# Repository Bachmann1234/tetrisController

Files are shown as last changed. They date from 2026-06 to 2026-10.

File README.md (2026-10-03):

# Tetris Controller

A split Tetris controller built around a Raspberry Pi Pico running CircuitPython. Presents itself as a USB keyboard so it works with any Tetris game (TETR.IO, Tetris Effect, Jstris, etc.) with no remapping required.

## Hardware

- Raspberry Pi Pico (RP2040) — lives in the right half
- 8 buttons, direct-wired (no matrix, no diodes)
- GX16-8 cable connecting the two halves
- LEDs are wired directly to power (no firmware control)

### Wiring

All buttons: **SW+ → GPIO**, **SW− → GND**. Internal pull-ups are enabled in firmware, so LOW = pressed.

| Button | GPIO | Half  | Key sent |
|---|---|---|---|
| Soft Drop | GP2  | Left  | Down Arrow |
| Right | GP3  | Left  | Right Arrow |
| Left | GP4  | Left  | Left Arrow |
| Hard Drop | GP5  | Left  | Space |
| Rotate CCW | GP6  | Right | Z |
| Rotate CW | GP7  | Right | X |
| Hold | GP8  | Right | C |
| Zone / Start | GP9  | Right | A |

The left-half buttons reach the Pico through the GX16-8 cable but are electrically identical to the right-half buttons.

## Enclosure: Printed by PCBWay

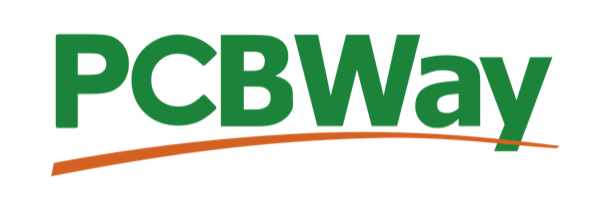
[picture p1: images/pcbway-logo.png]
PCBWay


[PCBWay](https://www.pcbway.com/) saw the first version of this controller and reached out about sponsoring a print. This inspired me to revise the design.

PCBWay is a prototyping and small-batch manufacturer. Along with PCB fabrication and assembly, they offer 3D printing (SLA, SLS, MJF, FDM, and metal), CNC machining, sheet metal, and injection molding.

I printed my first version in PETG on my Prusa Core One. It proved the layout, but it still looked like a prototype. For the next revision I wanted something that felt solid and a bit more professional.

### Ordering

I exported the box and button panel from Fusion 360. I went through the ordering process which felt intimidating at first but ultimately was pretty straightforward. I wanted something that I could not print myself so I went with Nylon PA12.

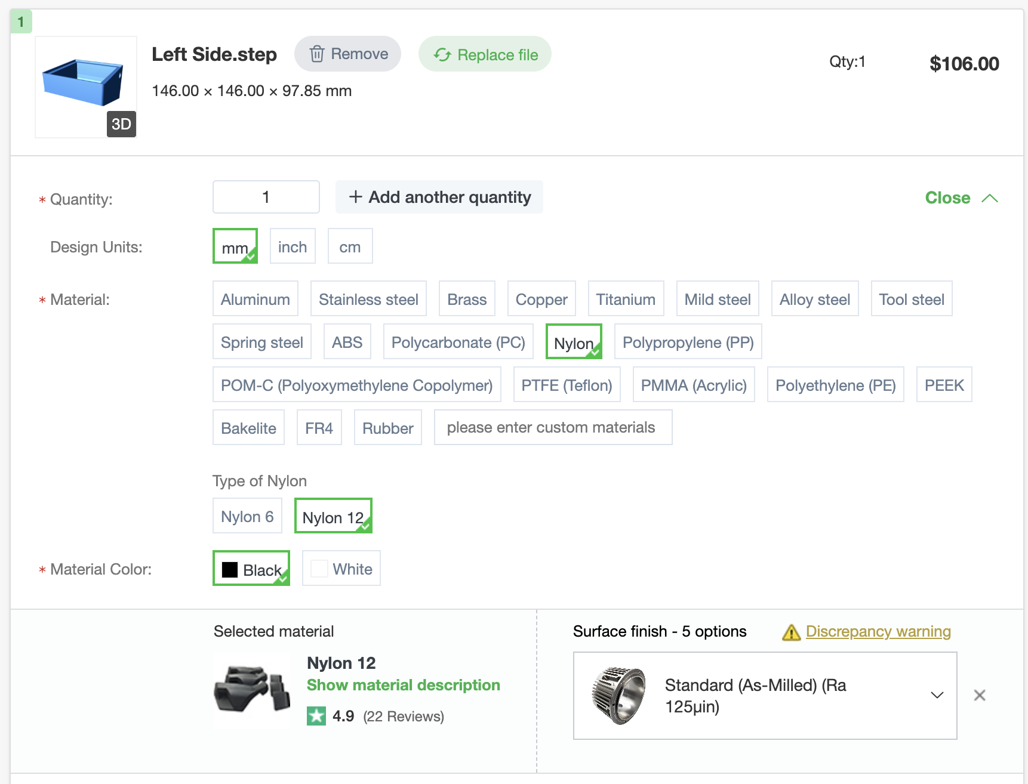
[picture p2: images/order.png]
Order Form


One of their engineers reached out and warned me that there was a chance of some warping. I was fine with this, since my tolerances were loose enough to absorb a little warping.

It was very comforting to get this feedback instead of just receiving the item and being disappointed in the results.

So far I've gotten the right side of the controller. It arrived in a nondescript box and was extremely well protected with foam. When I took it out I was really impressed. It looks incredible and it feels almost as if I had it printed in ceramic. I just love the feel and the sound when I tap it.

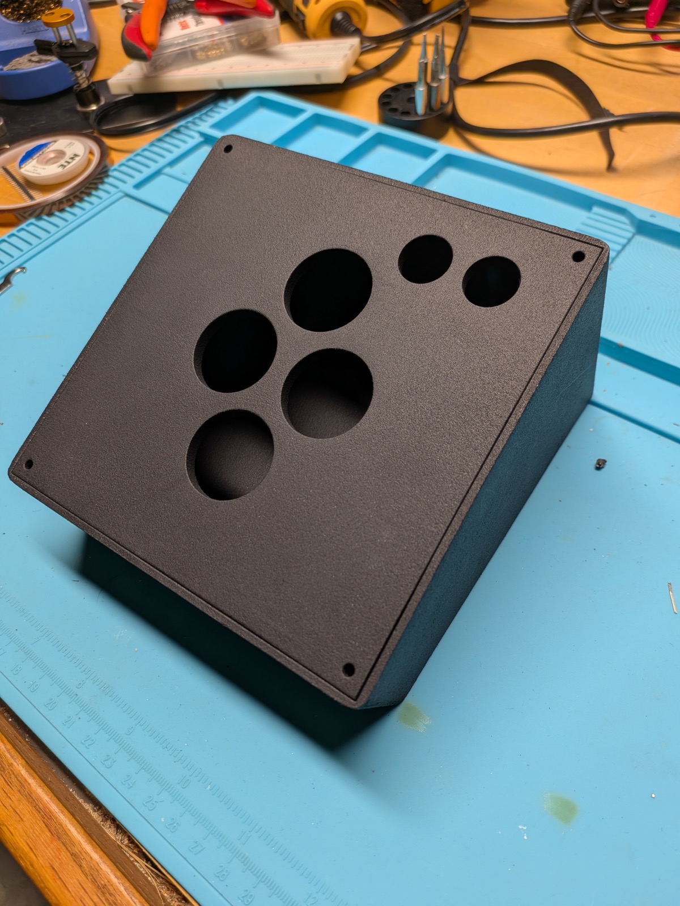
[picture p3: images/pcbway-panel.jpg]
Button panel seated on the box


The inside came out just as cleanly as the outside. The screw bosses on the Pico mounting rail are fully formed, and the rectangular USB cutout has sharp corners.

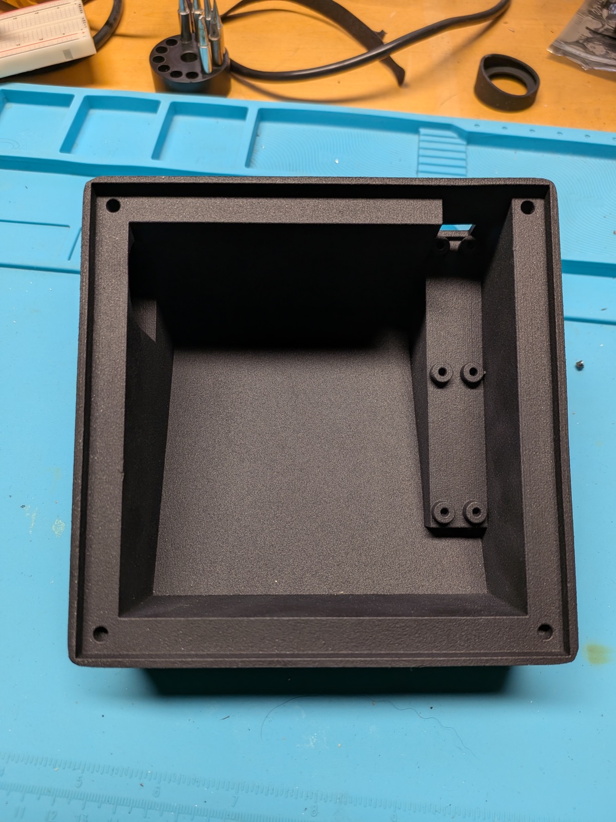
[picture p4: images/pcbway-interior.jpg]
Inside the box: Pico mounting rail, USB cutout, and panel lip


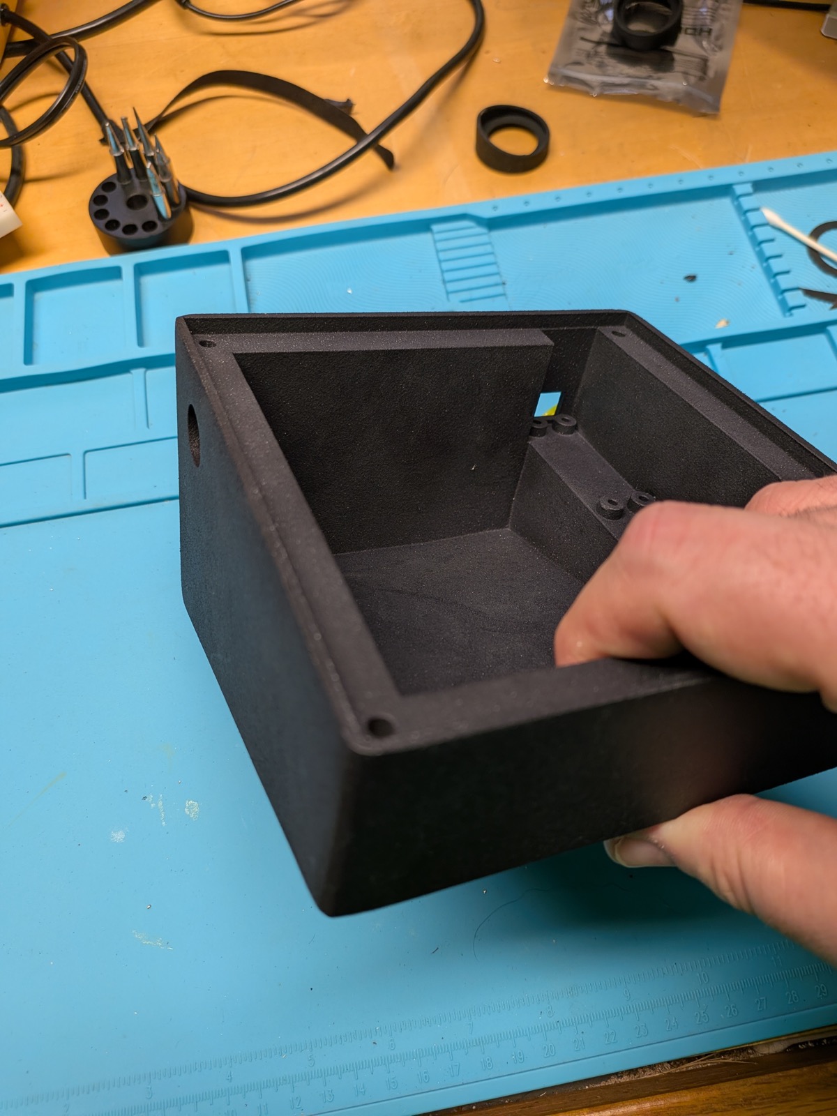
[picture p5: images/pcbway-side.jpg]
Side view showing the GX16-8 connector hole


The pieces fit together without any sanding, which was a relief. The button holes came out perfectly! They left no sign of supports.

I am looking forward to doing the second half and assembling the final piece. Once that is done I will have a controller that really changes how I play Tetris and other games.

### Why PCBWay

I have tried to get quotes for small projects. Small quantities are just not worth it to most manufacturers and the quotes come back in the thousands. PCBWay gives me an approachable way to make something just for me while having the quality of a professional product.

## Setup for a new Pico

### 1. Flash CircuitPython

1. Download the UF2 for your board:
   - Pico (original / Pico H): <https://circuitpython.org/board/raspberry_pi_pico/>
   - Pico 2: <https://circuitpython.org/board/raspberry_pi_pico2/>
2. Unplug the Pico. Hold the **BOOTSEL** button, then plug it into USB while still holding it.
3. Release BOOTSEL once the `RPI-RP2` drive appears.
4. Drag the `.uf2` file onto `RPI-RP2`. The Pico will reboot and a `CIRCUITPY` drive will appear.

### 2. Install the HID library

1. Download the CircuitPython library bundle matching your CircuitPython version: <https://circuitpython.org/libraries>
2. Unzip it.
3. Copy the `adafruit_hid/` folder from the bundle's `lib/` directory into `CIRCUITPY/lib/`.

That's all the dependencies. Don't bother with the bundle's `requirements/` folder — those are for desktop CPython usage, not for the Pico.

### 3. Copy firmware

Copy `boot.py` and `code.py` from this repo to the root of the `CIRCUITPY` drive.

### 4. Reboot

**Unplug and replug the Pico.** `boot.py` only takes effect on a full power cycle, not on a soft reload — without this step the keyboard HID device won't be registered.

After reboot the controller will appear as a generic USB keyboard. Pressing any button should send the corresponding key.

## Editing the firmware

Files live on the `CIRCUITPY` drive — edit them in place. Any editor works; some good options:

- **Mu Editor** — simplest, has built-in serial console for `print()` debugging.
- **VS Code** with the [CircuitPython v2 extension by wmerkens](https://marketplace.visualstudio.com/items?itemName=wmerkens.vscode-circuitpython-v2) — actively maintained fork of the original Adafruit-recommended extension.
- **Thonny** — also fine, popular in the Pico community.

Changes to `code.py` reload automatically. Changes to `boot.py` need a full unplug/replug.

## Customizing keybindings

Edit the `BUTTONS` table in `code.py`. Available keycodes are listed in `adafruit_hid/keycode.py` (also documented at <https://docs.circuitpython.org/projects/hid/en/latest/api.html>).

## Troubleshooting

- **No `CIRCUITPY` drive after flashing** — try a different USB cable (some are charge-only) or flash the [nuke UF2](https://learn.adafruit.com/getting-started-with-raspberry-pi-pico-circuitpython/troubleshooting) to wipe and start fresh.
- **Keyboard not detected** — make sure you fully unplugged and replugged after copying `boot.py`. A soft reset isn't enough.
- **`ImportError: no module named 'adafruit_hid'`** — confirm `adafruit_hid/` is in `CIRCUITPY/lib/`, not at the root.
- **Stuck keys / missed inputs** — check soldering on the suspect button; debounce is set to 10ms in `code.py` and can be tuned via `DEBOUNCE_SECS`.

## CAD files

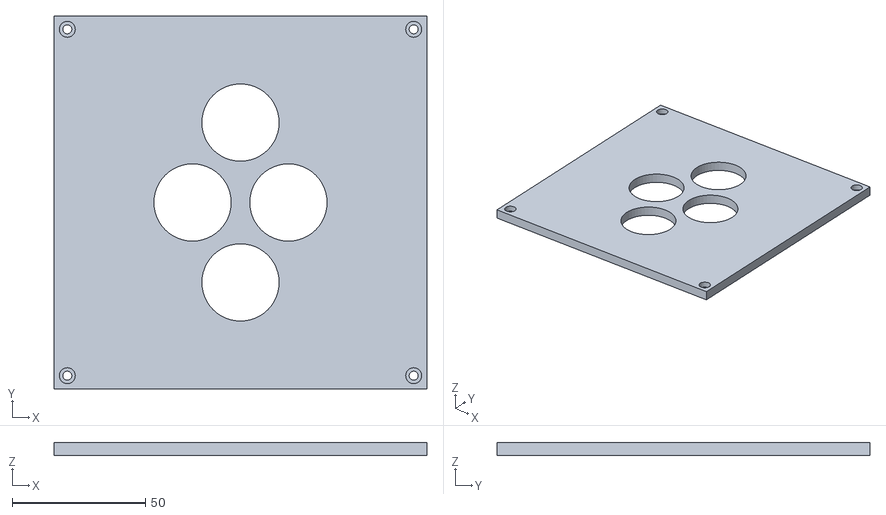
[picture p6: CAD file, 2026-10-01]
Left Button Panel.stl
140.0 x 140.0 x 5.00

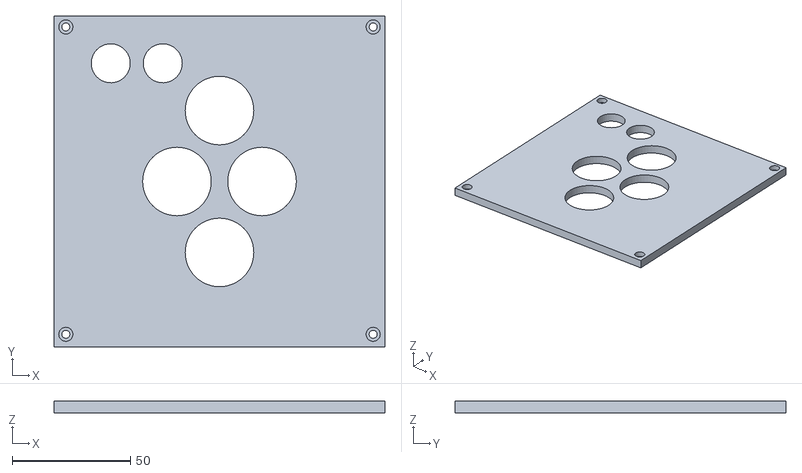
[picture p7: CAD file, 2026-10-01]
Right Button Panel.stl
140.0 x 140.0 x 5.00

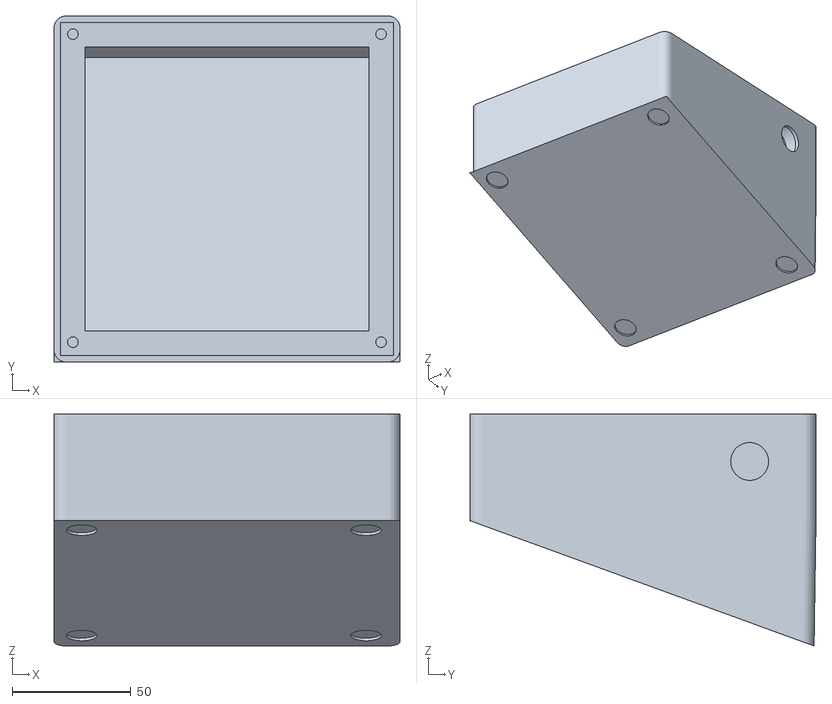
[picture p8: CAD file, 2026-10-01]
Left Box.stl
146.0 x 146.0 x 97.8

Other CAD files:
Right Box.stl

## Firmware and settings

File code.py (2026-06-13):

"""
code.py — Main loop for the Tetris split controller (keyboard mode).

Hardware: Raspberry Pi Pico running CircuitPython.
Wiring:  All 8 buttons direct-wired, SW+ to GPIO, SW- to GND.
         Internal pull-ups enabled — LOW = pressed.
         Left-half buttons arrive via GX16-8 cable but are
         electrically identical from the Pico's perspective.

Button-to-key map (matches TETR.IO / Tetris Effect defaults):
  GP2 = Soft Drop      → Down Arrow
  GP3 = Right          → Right Arrow
  GP4 = Left           → Left Arrow
  GP5 = Hard Drop      → Space
  GP6 = Rotate CCW     → Z
  GP7 = Rotate CW      → X
  GP8 = Hold           → C
  GP9 = Zone / Start   → A
"""

import board
import digitalio
import time
import usb_hid
from adafruit_hid.keyboard import Keyboard
from adafruit_hid.keycode import Keycode

# ---------- keyboard HID device ----------

kbd = Keyboard(usb_hid.devices)

# ---------- button definitions ----------

# (GPIO pin, keycode)
BUTTONS = (
    (board.GP2, Keycode.DOWN_ARROW),   # Soft Drop
    (board.GP3, Keycode.RIGHT_ARROW),  # Right
    (board.GP4, Keycode.LEFT_ARROW),   # Left
    (board.GP5, Keycode.SPACE),        # Hard Drop
    (board.GP6, Keycode.Z),            # Rotate CCW
    (board.GP7, Keycode.X),            # Rotate CW
    (board.GP8, Keycode.C),            # Hold
    (board.GP9, Keycode.A),            # Zone / Start
)

DEBOUNCE_SECS = 0.010  # 10 ms debounce

# ---------- set up GPIO inputs with pull-ups ----------

buttons = []
for pin, keycode in BUTTONS:
    dio = digitalio.DigitalInOut(pin)
    dio.direction = digitalio.Direction.INPUT
    dio.pull = digitalio.Pull.UP
    buttons.append((dio, keycode))

# ---------- debounce state ----------
# For each button: [stable_pressed, last_raw, last_change_time]
debounce = [
    [False, False, 0.0]
    for _ in buttons
]

# ---------- main loop ----------

while True:
    now = time.monotonic()

    for i, (dio, keycode) in enumerate(buttons):
        raw_pressed = not dio.value  # LOW = pressed (pull-up)
        state = debounce[i]

        if raw_pressed != state[1]:        # raw state changed
            state[1] = raw_pressed
            state[2] = now                 # reset timer

        if now - state[2] >= DEBOUNCE_SECS:
            if state[1] != state[0]:       # stable state changed
                state[0] = state[1]
                if state[0]:
                    kbd.press(keycode)
                else:
                    kbd.release(keycode)

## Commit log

2026-06-13 Initial commit: split Tetris controller firmware and enclosure
    CircuitPython firmware for a Raspberry Pi Pico that presents an 8-button
    split Tetris controller as a USB HID keyboard, plus 3MF enclosure models.
    [Box Left.3mf, Box Right.3mf, Button Panel.3mf]
2026-06-13 Add photo of the assembled controller to README
2026-10-01 Add PCBWay enclosure write-up and switch models to STL
    Document the revised enclosure printed by PCBWay in PA12 nylon, with
    photos of the order and the finished right half. Replace the .3mf
    source files with exported STLs for both halves and drop the old
    prototype photo.
    [Box Left.3mf, Box Right.3mf, Button Panel.3mf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]
